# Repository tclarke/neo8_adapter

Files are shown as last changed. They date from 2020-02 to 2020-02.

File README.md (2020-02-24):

# Breakout board for uBlock NEO-8 series. (NEO-8Q and NEO-M8)

This is a board designed to breakout pins on the uBlox NEO-8 GPS modules.
 - Solderless breadboard compatible
 - Edge-launch SMA for antenna and time pulse
 - Solder bridge to select UART or SPI
 - Solder bridge to enable/disable battery backup
 - Optional components for active (powered) antenna
 - Optional components for USB-C data
 - Optional components for USB-C power

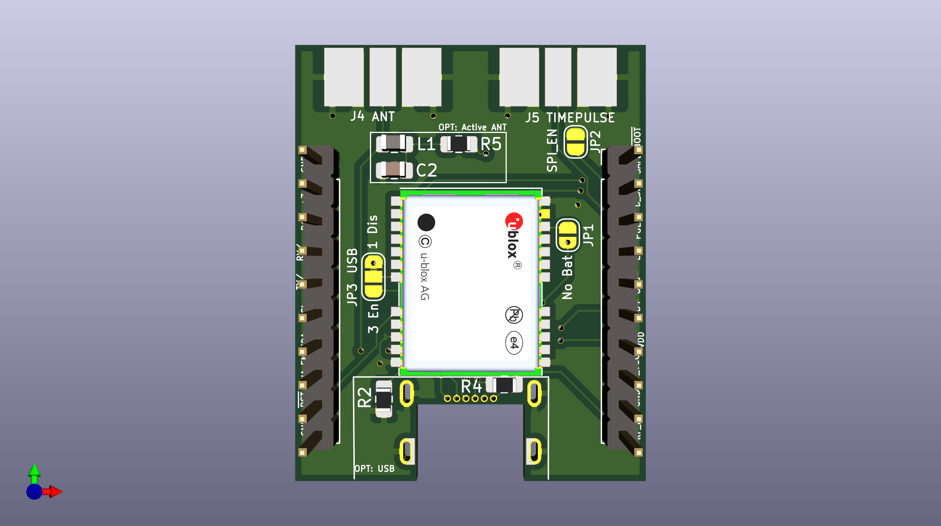
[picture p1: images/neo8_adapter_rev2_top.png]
Top of board Top of Board


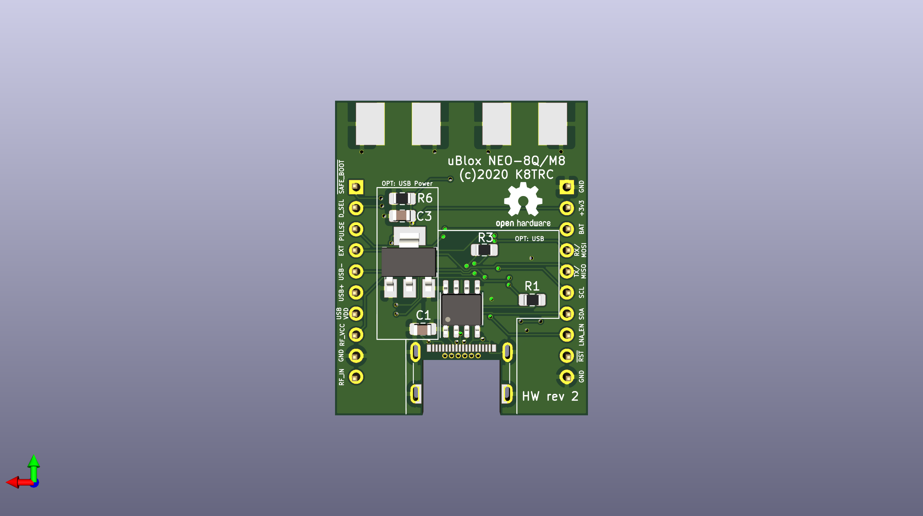
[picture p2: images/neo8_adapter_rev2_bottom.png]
Bottom of board Bottom of Board


## License
This design is licensed as [Open Source Hardware](http://www.oshwa.org/)

OSHW Logo

## Revision history
### Rev. 1
Initial revision of the board.

### Rev. 2
 - Add solder bridge documentation to the schematic
 - Add header pin labels to the PCB on the front and back
 - Tuning of solder mask markings for readability
 - Addition of solder mask markings to easily demarcate the optional sections

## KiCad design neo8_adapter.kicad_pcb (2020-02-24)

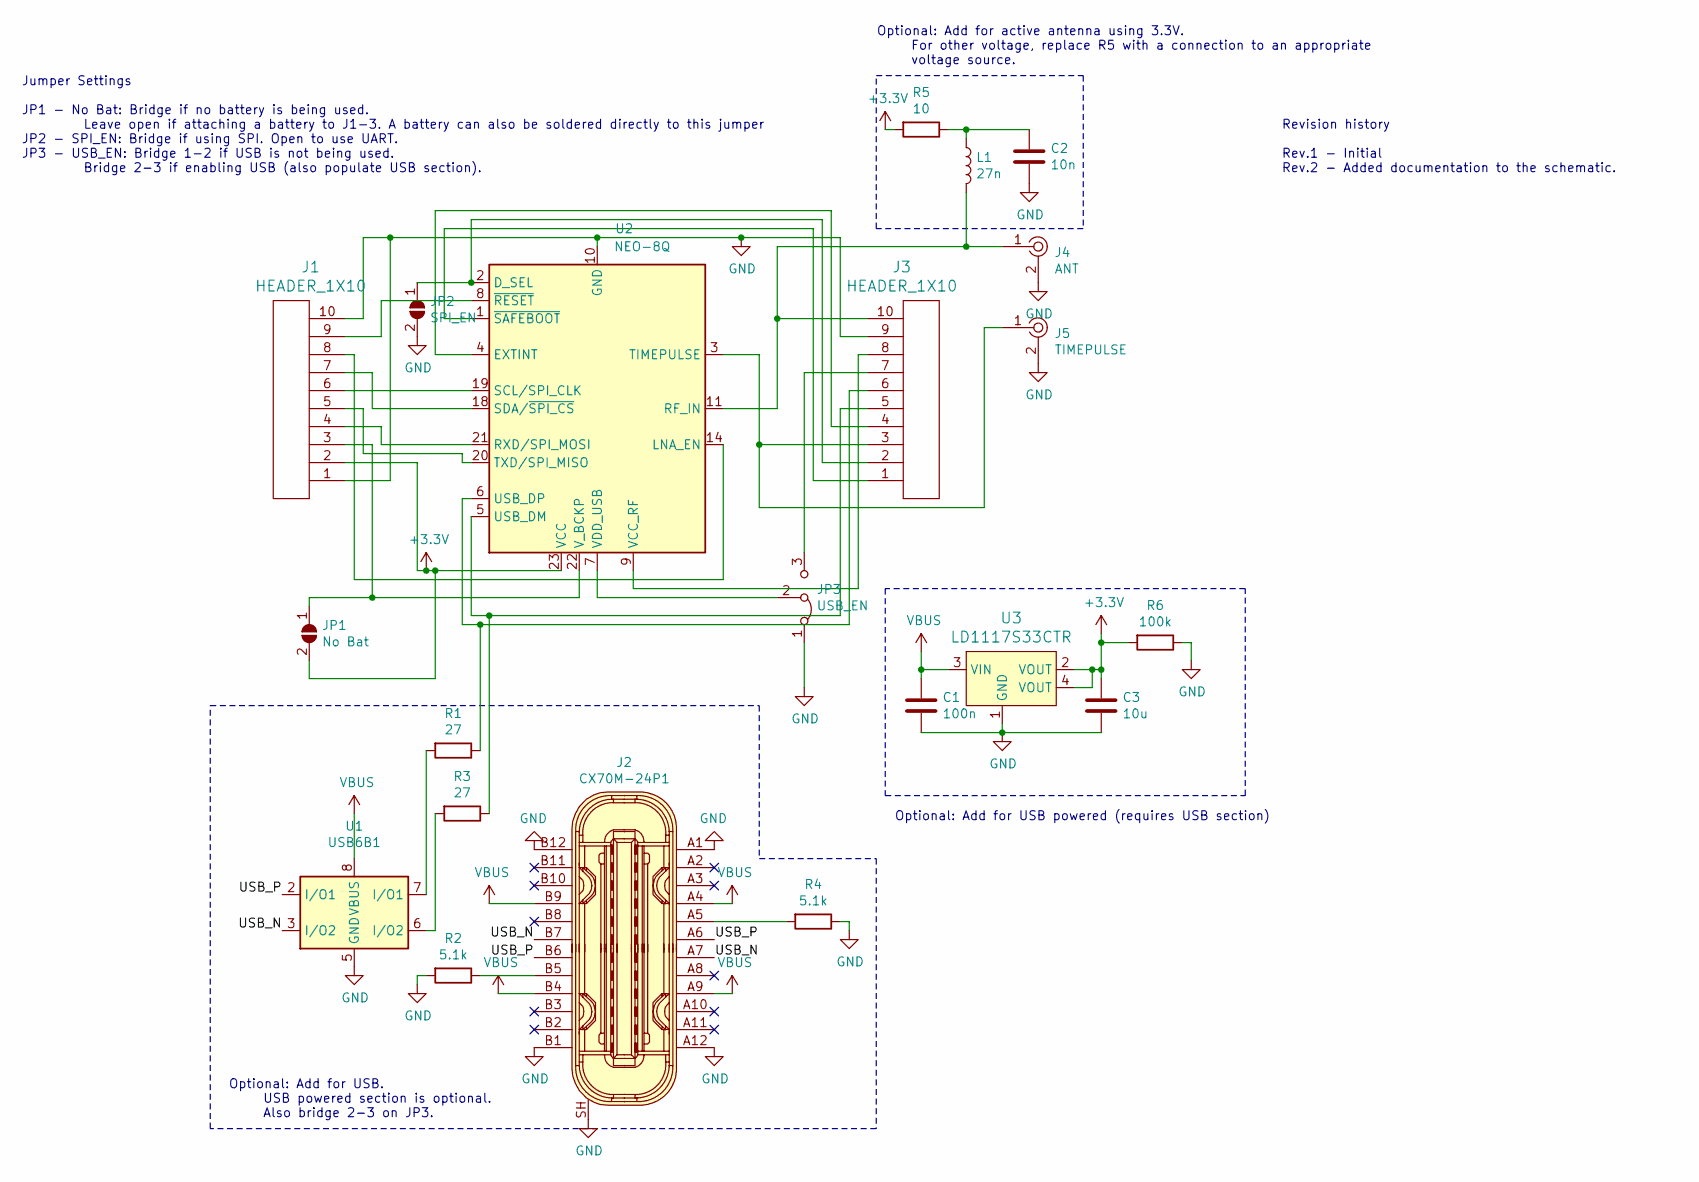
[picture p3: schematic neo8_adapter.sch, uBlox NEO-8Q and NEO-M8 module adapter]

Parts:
C1: 100n; C_0805_2012Metric_Pad1.15x1.40mm_HandSolder
C2: 10n; C_0805_2012Metric_Pad1.15x1.40mm_HandSolder
C3: 10u; C_0805_2012Metric_Pad1.15x1.40mm_HandSolder
J1, J3: HEADER_1X10; PinHeader_1x10_P2.54mm_Vertical
J2: CX70M-24P1; USB-C_Female_CX70M-24P1; MPN CX70M-24P1; Digi-Key_PN H125292CT-ND
J4: ANT; RF_SMA_BoardEdge_142-0701-801; MPN 142-0701-801; Digi-Key_PN J502-ND
J5: TIMEPULSE; RF_SMA_BoardEdge_142-0701-801; MPN 142-0701-801; Digi-Key_PN J502-ND
JP1: No Bat; SolderJumper-2_P1.3mm_Open_RoundedPad1.0x1.5mm
JP2: SPI_EN; SolderJumper-2_P1.3mm_Open_RoundedPad1.0x1.5mm
JP3: USB_EN; SolderJumper-3_P1.3mm_Bridged12_RoundedPad1.0x1.5mm_NumberL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
L1: 27n; L_0805_2012Metric_Pad1.15x1.40mm_HandSolder
R1, R3: 27; R_0805_2012Metric_Pad1.15x1.40mm_HandSolder
R2, R4: 5.1k; R_0805_2012Metric_Pad1.15x1.40mm_HandSolder
R5: 10; R_0805_2012Metric_Pad1.15x1.40mm_HandSolder
R6: 100k; R_0805_2012Metric_Pad1.15x1.40mm_HandSolder
U1: USB6B1; SOIC-8_3.9x4.9mm_P1.27mm
U2: NEO-8Q; ublox_NEO
U3: LD1117S33CTR; SOT-223; MPN LD1117S33CTR; Digi-Key_PN 497-1241-1-ND

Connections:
+3V3: C3.1, J1.2, JP1.2 (B), R5.2, R6.2, U2.23 (VCC), U3.2 (VOUT), U3.4 (VOUT)
/USB_N: J2.A7, J2.B7, U1.3 (I/O2)
/USB_P: J2.A6, J2.B6, U1.2 (I/O1)
GND: C1.2, C2.2, C3.2, J1.1, J1.10, J2.A1, J2.A12, J2.B1, J2.B12, J2.SH, J3.9, J4.2, J5.2, JP2.2 (B), JP3.1 (A), R2.2, R4.1, R6.1, U1.4 (GND), U1.5 (GND), U2.10 (GND), U2.12 (GND), U2.13 (GND), U2.24 (GND), U3.1 (GND)
unnamed: C2.1, L1.1, R5.1
unnamed: J1.3, JP1.1 (A), U2.22 (V_BCKP)
unnamed: J1.4, U2.21 (RXD/SPI_MOSI)
unnamed: J1.5, U2.20 (TXD/SPI_MISO)
unnamed: J1.6, U2.19 (SCL/SPI_CLK)
unnamed: J1.7, U2.18 (SDA/~SPI_CS)
unnamed: J1.8, U2.14 (LNA_EN)
unnamed: J1.9, U2.8 (~RESET)
unnamed: J2.A5, R4.2
unnamed: J2.B5, R2.1
unnamed: J3.1, U2.1 (~SAFEBOOT)
unnamed: J3.2, JP2.1 (A), U2.2 (D_SEL)
unnamed: J3.3, J5.1, U2.3 (TIMEPULSE)
unnamed: J3.4, U2.4 (EXTINT)
unnamed: J3.5, R3.1, U2.5 (USB_DM)
unnamed: J3.6, R1.1, U2.6 (USB_DP)
unnamed: J3.7, JP3.3 (B)
unnamed: J3.8, U2.9 (VCC_RF)
unnamed: J3.10, J4.1, L1.2, U2.11 (RF_IN)
unnamed: JP3.2 (C), U2.7 (VDD_USB)
unnamed: R1.2, U1.7 (I/O1)
unnamed: R3.2, U1.6 (I/O2)
VBUS: C1.1, J2.A4, J2.A9, J2.B4, J2.B9, U1.1 (VBUS), U1.8 (VBUS), U3.3 (VIN)

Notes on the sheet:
Optional: Add for active antenna using 3.3V. For other voltage, replace R5 with a connection to an appropriate voltage source.
Optional: Add for USB. USB powered section is optional. Also bridge 2-3 on JP3.
Optional: Add for USB powered (requires USB section)
Jumper Settings JP1 - No Bat: Bridge if no battery is being used. Leave open if attaching a battery to J1-3. A battery can also be soldered directly to this jumper JP2 - SPI_EN: Bridge if using SPI. Open to use UART. JP3 - USB_EN: Bridge 1-2 if USB is not being used. Bridge 2-3 if enabling USB (als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
Revision history Rev.1 - Initial Rev.2 - Added documentation to the schematic.

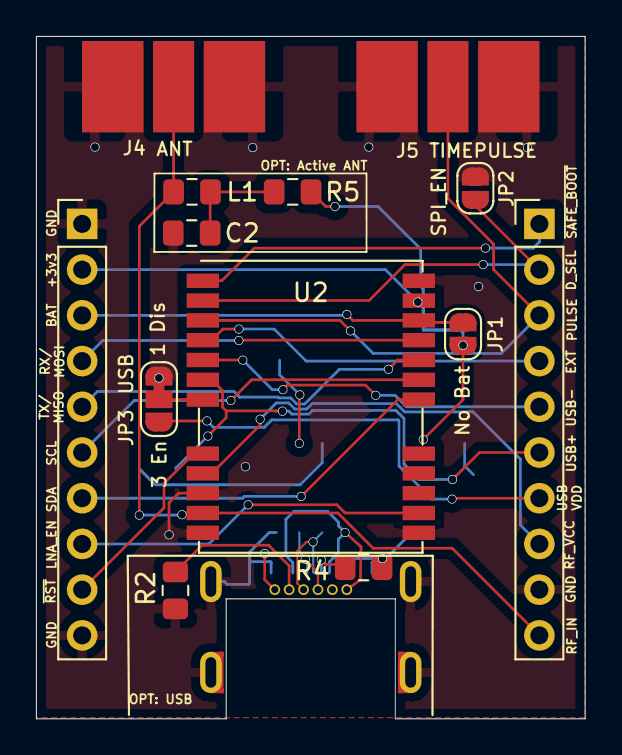
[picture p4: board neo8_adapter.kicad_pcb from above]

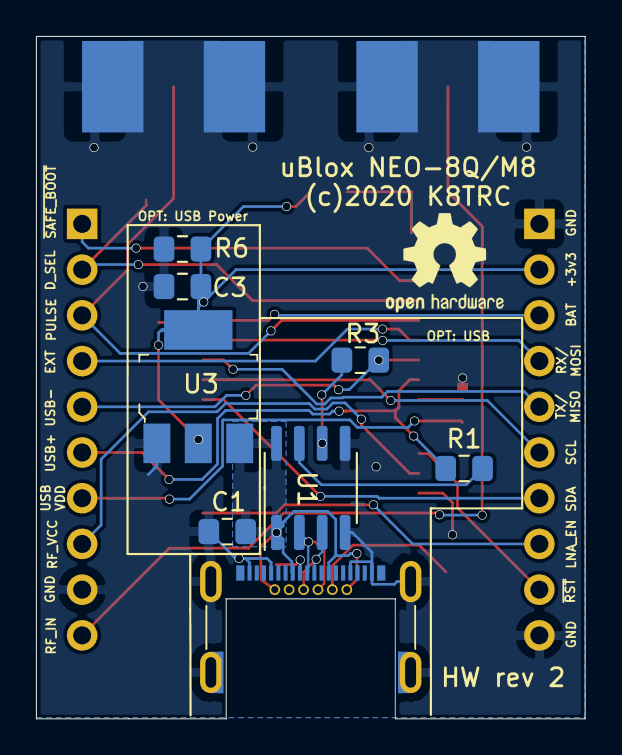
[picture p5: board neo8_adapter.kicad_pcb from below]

Board: 2 copper layers, 30.5 x 37.9 mm, 21 parts (8 on the bottom side), 27 nets.

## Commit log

2020-02-24 Initial checkin. Contains rev.2 schematic and pcb but rev.1 Gerbers
    [neo8_adapter-B_Cu.gbl, neo8_adapter-B_Mask.gbs, neo8_adapter-B_Paste.gbp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]
2020-02-24 Add a readme and associated board images

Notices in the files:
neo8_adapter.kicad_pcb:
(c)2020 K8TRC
